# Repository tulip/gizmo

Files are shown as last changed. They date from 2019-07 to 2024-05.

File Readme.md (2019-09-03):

# Micro Word Clock v2

## Arduino IDE setup (must do for programming with AVRISP and Arduino)
- Download the latest version of the [Arduino IDE](https://www.arduino.cc/en/main/software)
- `cd ~/Documents/Arduino && mkdir hardware`
- cd into `hardware` clone [this repository](https://github.com/carlosefr/atmega) into it
- Restart the Arduino IDE, you should see `Tools > Board > ATMega328` and some other things show up
<p align="center">
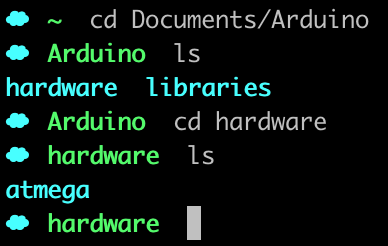
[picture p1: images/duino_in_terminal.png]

</p>

## Upload instructions with AVRISP MKII programmer

##### Burning the bootloader
- Plug in the Gizmo so that it is powered externally - the AVRISP MKII will **not** work if it is not powered externally
- Plug in the AVRISP, select `Tools > Programmer > AVRISP mkII`
- Plug in ICSP header from AVRISP to ICSP header on Gizmo (ICSP labels on Gizmo are on back of board)
- Select `Tools > Board > ATmega328/328p`
- Select `Tools > Processor > ATmega328p`
- Select `Tools > Clock > Internal 8 MHz`
- If everything is good, you should see a green light at the bottom of the programmer.
- Select `Tools > Burn Bootloader`
- If the programmer is working, you should see a second green light flash as it is programming. 

<p align="center">
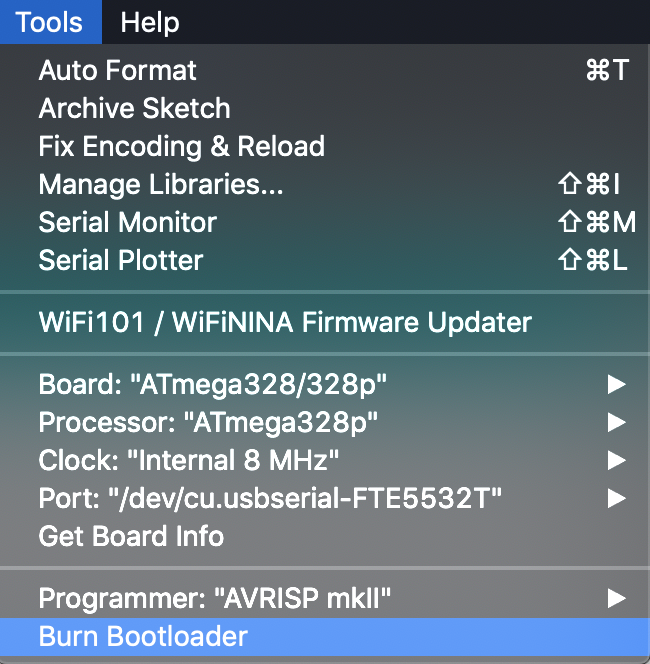
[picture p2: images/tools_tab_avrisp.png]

</p>

##### Uploading sketch
- Open `MicroWordClock2-Arduino.ino` in Arduino IDE
- Select `Sketch > Upload Using Programmer`
<p align="center">
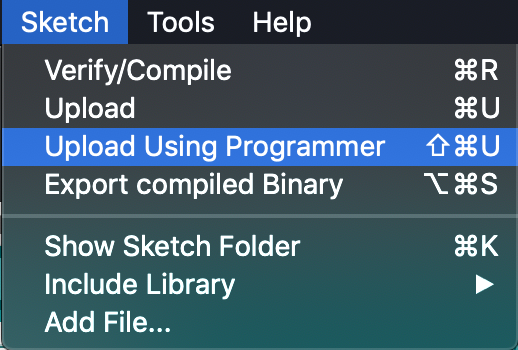
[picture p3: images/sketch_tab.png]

</p>

## Upload instructions with Arduino Uno

##### Setting up the Arduino Uno as an ISP
- Plug in the Arduino, select `Tools > Programmer > Arduino as ISP` and `Tools > Board > Arduino/Genuino Uno`
- Select `File > Examples > ArduinoISP` and see a new script open
- Make sure that the correct port is selected in `Tools > Port`
- On the top left corner of the window, select upload
<p align="center">
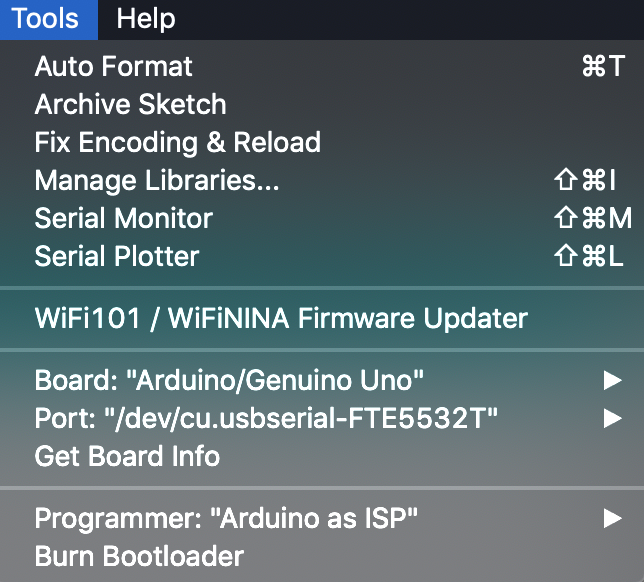
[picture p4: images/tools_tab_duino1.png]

</p>

##### Burning the Bootloader
- Wire up the Arduino to Gizmo's ICSP header, but make sure to wire up power last (Gizmo has the standard ICSP header configuration). Use the following wiring:

| Arduino pin | ICSP header pin |
|---|---|
| 10 | RESET |
| 11 | MOSI |
| 12 | MISO |
| 13 | SCK |
| 5 V | VCC |
| GND | GND |

- Connect a 10uF capacitor between Arduino's RESET pin and GND
- Select `Tools > Board > ATmega328/328p`
- Select `Tools > Processor > ATmega328p`
- Select `Tools > Clock > Internal 8 MHz`
- Select `Tools > Burn Bootloader`
<p align="center">
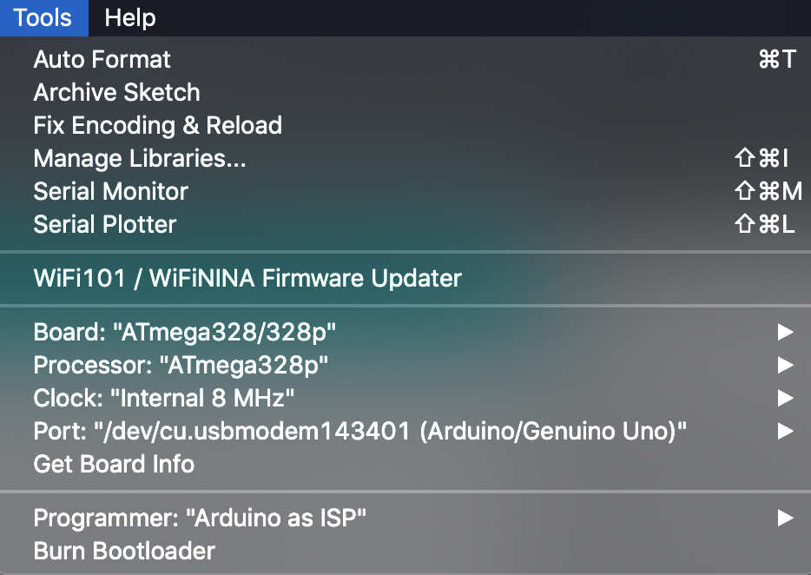
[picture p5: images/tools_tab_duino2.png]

</p>

##### Uploading sketch
- Open `MicroWordClock2-Arduino.ino` in Arduino IDE
- With cap still plugged in and same `Tools` settings as before, select `Sketch > Upload Using Programmer`
- The TX and RX LEDs on the Arduino should start blinking, all LEDs on the Gizmo board should light up initially, then the board should be good to go

##### Troubleshooting 
- Make sure the correct option is selected under `Tools > Board` - should be Arduino Uno only when uploading ISP sketch
- Make sure the connections to the 10uF cap are good - I plugged it into a breadboard and used jumper wires to connect
- If nothing's working, try power cycling

## Setting the time 
- Once the sketch is uploaded, unplug the Arduino/programmer and plug in Gizmo's independent power supply
- Hold down SW1 until words start blinking. To cycle through "quarter past", "half past", etc., press SW1 the number of minutes you want to increment past the time designator
- To set the hour, hold down SW1 again until the current hour starts blinking and cycle through. Once you're done, hold down SW1 until only one LED blinks again

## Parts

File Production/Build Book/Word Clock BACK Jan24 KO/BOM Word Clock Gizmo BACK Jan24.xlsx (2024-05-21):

Reference Designator | Part | MFR | MPN | Link (Old) | Quantity | Notes
U$1, U$2, U$3, U$4, U$5, U$6, U$7, U$8, U$9, U$10, U$11, U$12, U$13, U$14, U$15, U$16, U$17, U$18, U$19, U$20, U$21, U$22, U$23, U$24, U$25, U$26, U$27, U$28, U$29, U$30, U$31, U$32, U$33, U$34, U$35, U$37, U$38, U$39, U$40, U$41, U$42, U$43, U$44, U$45, U$46, U$47, U$48, U$49, U$50, U$51, U$52, U$53, U$54, U$55, U$56, U$57, U$58, U$59, U$60, U$61, U$62, U$63, U$64 | LEDs | Cree | JE2835AWT-00-0000-0B0A0BG840E | https://www.digikey.com/product-detail/en/cree-inc/JE2835AWT-00-0000-0B0A0BG840E/JE2835AWT-00-0000-0B0A0BG840ETR-ND/9974650 | 63
S1 | Switch | TE Connectivity Alcoswitch Switches | 1-1825027-1 | https://www.digikey.com/product-detail/en/te-connectivity-alcoswitch-switches/1-1825027-1/450-1658-ND/1632544 | 1
U1 | ATmega328P | Microchip | ATmega328P-AU | https://www.alibaba.com/product-detail/integrated-circuit-ATMEGA328P-AU-Microcontroller-flash_60826153173.html | 1
J3 | 2x3 0.1'' Header Pin | Adam Tech | PH2-06-UA | https://www.digikey.com/product-detail/en/adam-tech/PH2-06-UA/2057-PH2-06-UA-ND/9830396 | 1
J1 | 1x5 0.1" Header Pin (Male) | Adam Tech | PH1-05-UA | https://www.digikey.com/product-detail/en/adam-tech/PH1-05-UA/2057-PH1-05-UA-ND/9830343 | 1
- | 1x8 0.1" Header Pin (Male) | HOUAC | 1625-1140CNG0S150001 |  | 4 | Installed in J4/J5/J6/J7 during assembly.
J4, J5, J6, J7 | 1x8 0.1" Header Pin (Female) | Sullins Connector Solutions | PPTC081LFBN-RC | https://www.digikey.com/product-detail/en/sullins-connector-solutions/PPTC081LFBN-RC/S7006-ND/810147 | 4
R1, R2, R3, R4, R5, R6, R7, R8 | 0603 51ohm Resistor | Bourns Inc. | CR0603-JW-510ELF | https://www.digikey.com/product-detail/en/bourns-inc/CR0603-JW-510ELF/CR0603-JW-510ELFCT-ND/3925369 | 8
R9 | 0603 1M Resistor | Vishay Beyschlag | MCT0603-1.00M-CFCT | https://www.digikey.com/product-detail/en/vishay-beyschlag/MCT06030C1004FP500/MCT0603-1.00M-CFCT-ND/2607877 | 1
L1 | 0603 120 Ohm Ferrite Bead | TDK | MAF1608GAD601CT000 | https://www.mouser.com/ProductDetail/TDK/MAF1608GAD601CT000 | 1
C1 | 0603 220 nF Capacitor | Samsung Electro-Mechanics | CL10B224KP8NNNC | https://www.digikey.com/product-detail/en/samsung-electro-mechanics/CL10B224KP8NNNC/1276-2014-2-ND/3887672 | 1
C3 | 0603 4700 pF Capacitor | Samsung Electro-Mechanics | CL10B472KB8NNNC | https://www.digikey.com/product-detail/en/samsung-electro-mechanics/CL10B472KB8NNNC/1276-1098-2-ND/3886756 | 1
C4 | 0603 4.7 uF Capacitor | Samsung Electro-Mechanics | CL10A475MQ8NNNC | https://www.digikey.com/product-detail/en/samsung-electro-mechanics/CL10A475MQ8NNNC/1276-1907-1-ND/3889993 | 1
C2 | 2.2uF Capacitor | Samsung Electro-Mechanics | CL10A225KQ8NNWC | https://www.digikey.com/product-detail/en/samsung-electro-mechanics/CL10A225KQ8NNWC/1276-1886-2-ND/3887544 | 1
J2 | MicroUSB Jack | Amphenol ICC FCI | 10118193-0001LF | https://www.digikey.com/product-detail/en/amphenol-icc-fci/10118193-0001LF/609-4616-2-ND/2785388 | 1
- | Real-Time Clock & Battery |  | REF FILE 'RTC CANDIDATES' | https://www.amazon.com/HiLetgo-DS3231-Precision-Arduino-Raspberry/dp/B01N1LZSK3 | 1 | Can use same as last production, requirements: DS3231 RTC, 4 Female Pin With Battery. Please assemble onto PCB (unlike last production)
- | MicroUSB Cable | Shenzhen Hezhongxin Electronics Co., Ltd | HSX-003M | https://www.alibaba.com/product-detail/small-USB-shielded-high-speed-2_62016105964.html?s=p | 1 | Alternate Part Requested, requirements: ~90CM, Black, USB-A Male <> Micro-USB Male, Low-Cost

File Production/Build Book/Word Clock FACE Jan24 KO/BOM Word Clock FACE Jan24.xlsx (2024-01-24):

Reference Designator | Part | Quantity | MFR | MPN | Notes
J1, J2, J3, J4 | 1x8 0.1" Header Pin (Female) | 4 | SparkFun | PRT-11543 | Part Discontinued: Potential Alt SparkFun PRT-21471, but needs verification. Other Alt Parts are also OK. Waiting for drawing from manufacturer.

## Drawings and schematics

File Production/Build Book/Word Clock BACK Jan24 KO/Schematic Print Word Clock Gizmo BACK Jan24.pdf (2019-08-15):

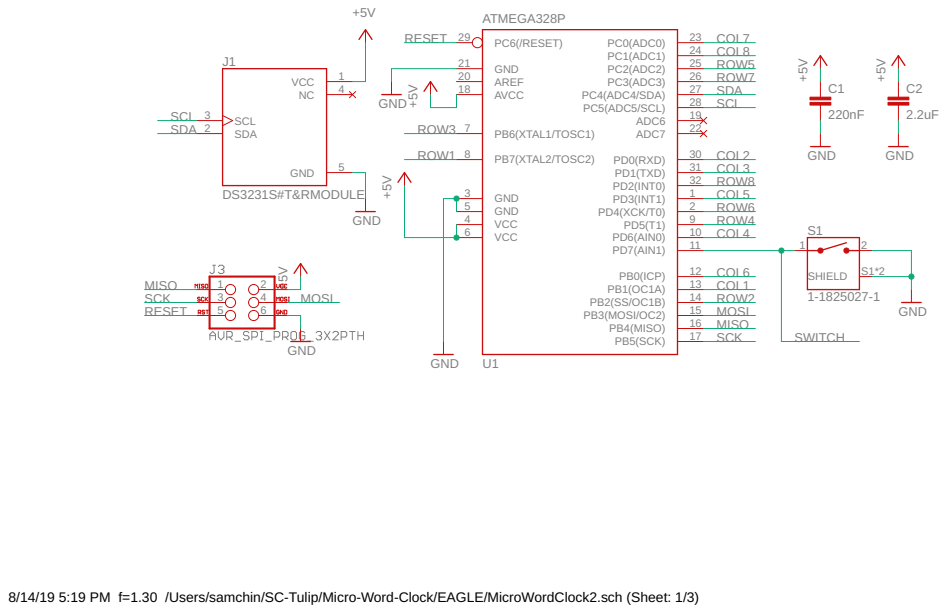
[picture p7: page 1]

8/14/19 5:19 PM f=1.30 /Users/samchin/SC-Tulip/Micro-Word-Clock/EAGLE/MicroWordClock2.sch (Sheet: 1/3)

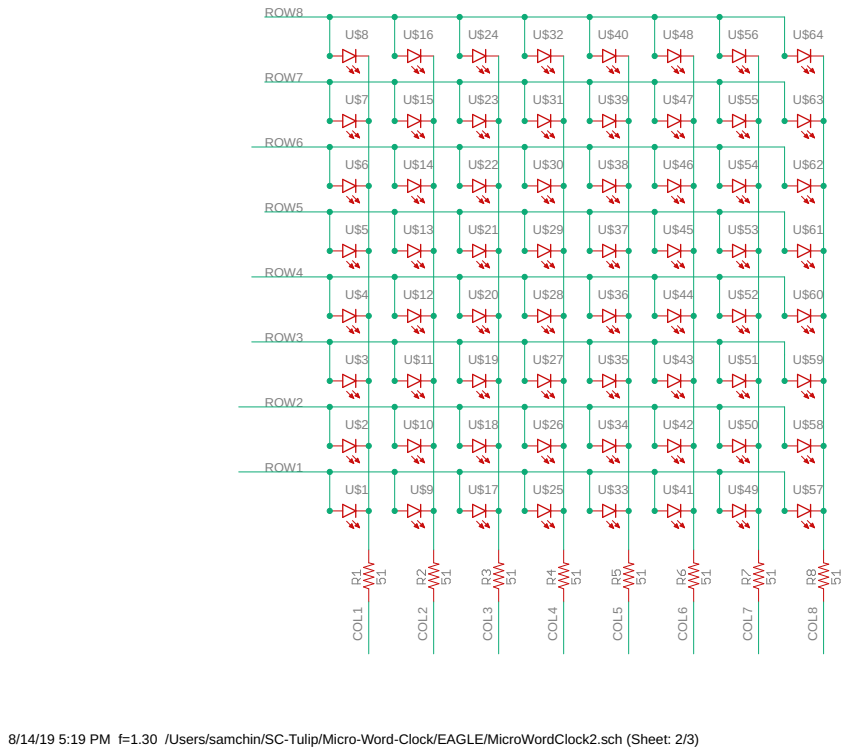
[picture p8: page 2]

8/14/19 5:19 PM f=1.30 /Users/samchin/SC-Tulip/Micro-Word-Clock/EAGLE/MicroWordClock2.sch (Sheet: 2/3)

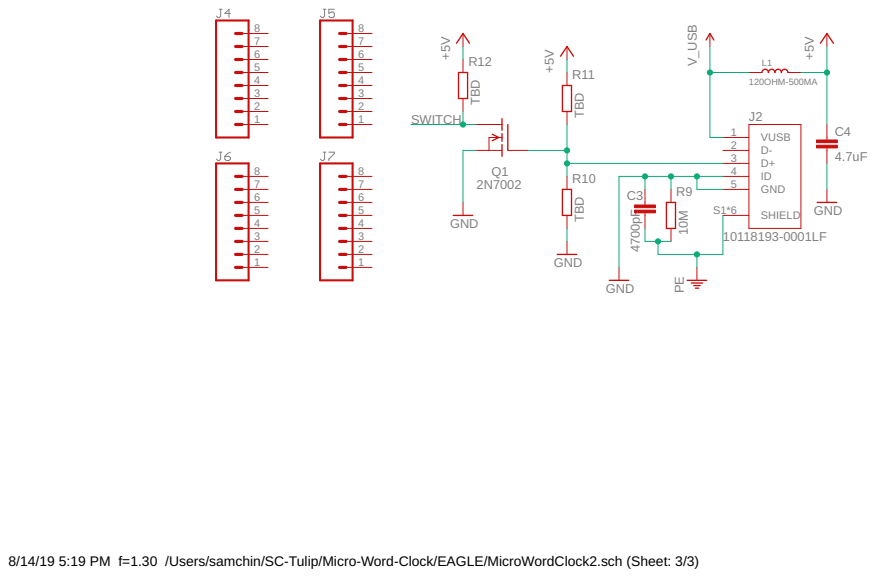
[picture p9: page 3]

8/14/19 5:19 PM f=1.30 /Users/samchin/SC-Tulip/Micro-Word-Clock/EAGLE/MicroWordClock2.sch (Sheet: 3/3)

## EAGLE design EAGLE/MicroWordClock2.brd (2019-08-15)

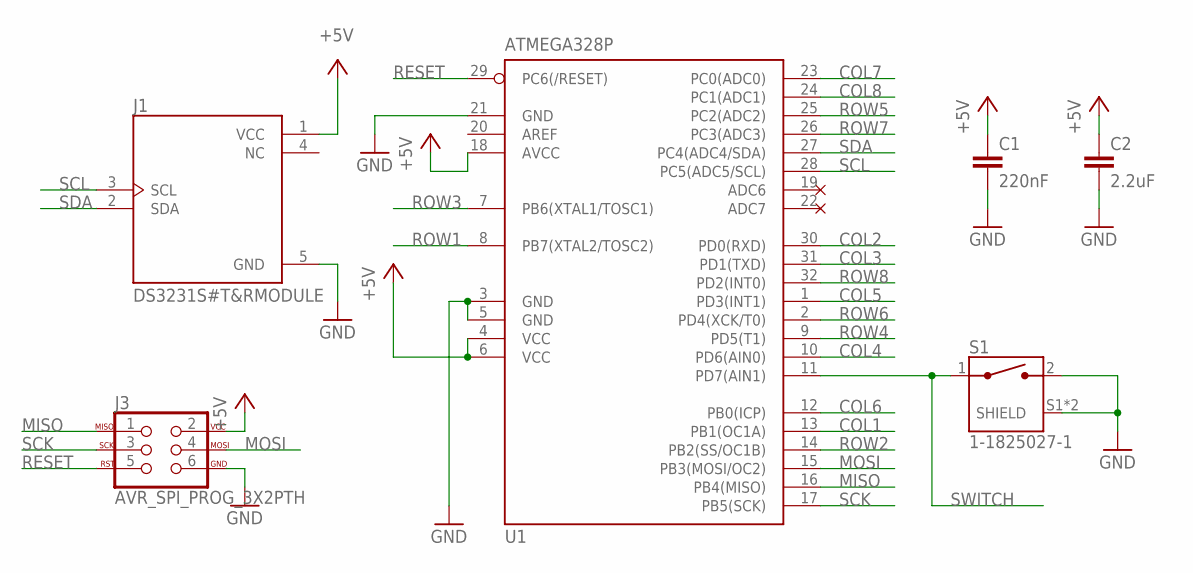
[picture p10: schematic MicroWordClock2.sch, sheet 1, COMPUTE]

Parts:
C1: 220nF; C0603
C2: 2.2uF; C0603
J1: DS3231S#T&RMODULE; 1X05
J3: AVR_SPI_PROG_3X2PTH; 2X3
S1: 1-1825027-1; SW_1-1825027-1
U1: ATMEGA328P; TQFP32-08

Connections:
+5V: C1.1, C2.1, J1.1 (VCC), J3.2, U1.4 (VCC), U1.6 (VCC), U1.18 (AVCC); also elsewhere on the board
COL1: U1.13 (PB1(OC1A)); also elsewhere on the board
COL2: U1.30 (PD0(RXD)); also elsewhere on the board
COL3: U1.31 (PD1(TXD)); also elsewhere on the board
COL4: U1.10 (PD6(AIN0)); also elsewhere on the board
COL5: U1.1 (PD3(INT1)); also elsewhere on the board
COL6: U1.12 (PB0(ICP)); also elsewhere on the board
COL7: U1.23 (PC0(ADC0)); also elsewhere on the board
COL8: U1.24 (PC1(ADC1)); also elsewhere on the board
GND: C1.2, C2.2, J1.5 (GND), J3.6, S1.2, S1.S1 (SHIELD), S1.S2 (SHIELD), U1.3 (GND), U1.5 (GND), U1.21 (GND); also elsewhere on the board
MISO: J3.1, U1.16 (PB4(MISO))
MOSI: J3.4, U1.15 (PB3(MOSI/OC2))
RESET: J3.5, U1.29 (PC6(/RESET))
ROW1: U1.8 (PB7(XTAL2/TOSC2)); also elsewhere on the board
ROW2: U1.14 (PB2(SS/OC1B)); also elsewhere on the board
ROW3: U1.7 (PB6(XTAL1/TOSC1)); also elsewhere on the board
ROW4: U1.9 (PD5(T1)); also elsewhere on the board
ROW5: U1.25 (PC2(ADC2)); also elsewhere on the board
ROW6: U1.2 (PD4(XCK/T0)); also elsewhere on the board
ROW7: U1.26 (PC3(ADC3)); also elsewhere on the board
ROW8: U1.32 (PD2(INT0)); also elsewhere on the board
SCK: J3.3, U1.17 (PB5(SCK))
SCL: J1.3 (SCL), U1.28 (PC5(ADC5/SCL))
SDA: J1.2 (SDA), U1.27 (PC4(ADC4/SDA))
SWITCH: S1.1, U1.11 (PD7(AIN1)); also elsewhere on the board

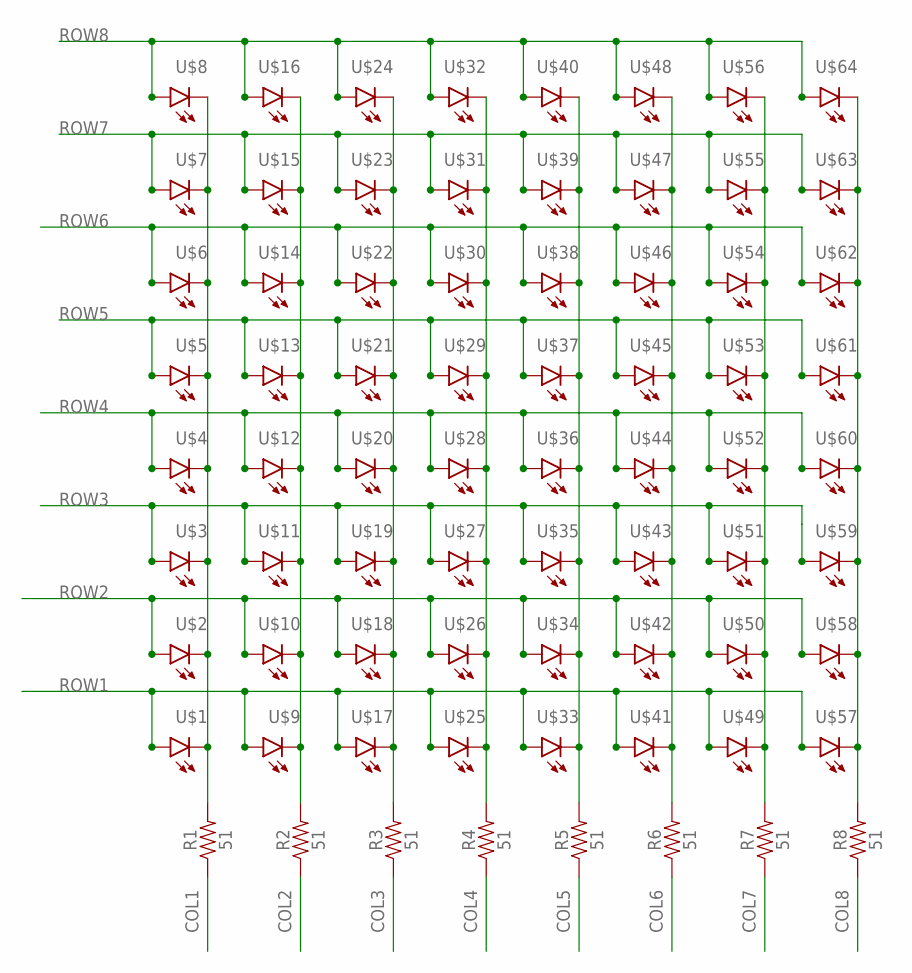
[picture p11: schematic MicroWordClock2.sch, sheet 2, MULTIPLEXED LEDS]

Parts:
R1, R2, R3, R4, R5, R6, R7, R8: 51; 0603
U$1, U$2, U$3, U$4, U$5, U$6, U$7, U$8, U$9, U$10, U$11, U$12, U$13, U$14, U$15, U$16, U$17, U$18, U$19, U$20, U$21, U$22, U$23, U$24, U$25, U$26, U$27, U$28, U$29, U$30, U$31, U$32, U$33, U$34, U$35, U$36, U$37, U$38, U$39, U$40, U$41, U$42, U$43, U$44, U$45, U$46, U$47, U$48, U$49, U$50, U$51, U$52, U$53, U$54, U$55, U$56, U$57, U$58, U$59, U$60, U$61, U$62, U$63, U$64: WHITE; 1113(2835METRIC)

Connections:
COL1: R1.1; also elsewhere on the board
COL2: R2.1; also elsewhere on the board
COL3: R3.1; also elsewhere on the board
COL4: R4.1; also elsewhere on the board
COL5: R5.1; also elsewhere on the board
COL6: R6.1; also elsewhere on the board
COL7: R7.1; also elsewhere on the board
COL8: R8.1; also elsewhere on the board
EE: R8.2, U$57.CATHODE (C), U$58.CATHODE (C), U$59.CATHODE (C), U$60.CATHODE (C), U$61.CATHODE (C), U$62.CATHODE (C), U$63.CATHODE (C), U$64.CATHODE (C)
unnamed: R3.2, U$17.CATHODE (C), U$18.CATHODE (C), U$19.CATHODE (C), U$20.CATHODE (C), U$21.CATHODE (C), U$22.CATHODE (C), U$23.CATHODE (C), U$24.CATHODE (C)
unnamed: R4.2, U$25.CATHODE (C), U$26.CATHODE (C), U$27.CATHODE (C), U$28.CATHODE (C), U$29.CATHODE (C), U$30.CATHODE (C), U$31.CATHODE (C), U$32.CATHODE (C)
unnamed: R5.2, U$33.CATHODE (C), U$34.CATHODE (C), U$35.CATHODE (C), U$36.CATHODE (C), U$37.CATHODE (C), U$38.CATHODE (C), U$39.CATHODE (C), U$40.CATHODE (C)
unnamed: R6.2, U$41.CATHODE (C), U$42.CATHODE (C), U$43.CATHODE (C), U$44.CATHODE (C), U$45.CATHODE (C), U$46.CATHODE (C), U$47.CATHODE (C), U$48.CATHODE (C)
unnamed: R7.2, U$49.CATHODE (C), U$50.CATHODE (C), U$51.CATHODE (C), U$52.CATHODE (C), U$53.CATHODE (C), U$54.CATHODE (C), U$55.CATHODE (C), U$56.CATHODE (C)
unnamed: R1.2, U$1.CATHODE (C), U$2.CATHODE (C), U$3.CATHODE (C), U$4.CATHODE (C), U$5.CATHODE (C), U$6.CATHODE (C), U$7.CATHODE (C), U$8.CATHODE (C)
unnamed: R2.2, U$9.CATHODE (C), U$10.CATHODE (C), U$11.CATHODE (C), U$12.CATHODE (C), U$13.CATHODE (C), U$14.CATHODE (C), U$15.CATHODE (C), U$16.CATHODE (C)
ROW1: U$1.ANODE (A), U$9.ANODE (A), U$17.ANODE (A), U$25.ANODE (A), U$33.ANODE (A), U$41.ANODE (A), U$49.ANODE (A), U$57.ANODE (A); also elsewhere on the board
ROW2: U$2.ANODE (A), U$10.ANODE (A), U$18.ANODE (A), U$26.ANODE (A), U$34.ANODE (A), U$42.ANODE (A), U$50.ANODE (A), U$58.ANODE (A); also elsewhere on the board
ROW3: U$3.ANODE (A), U$11.ANODE (A), U$19.ANODE (A), U$27.ANODE (A), U$35.ANODE (A), U$43.ANODE (A), U$51.ANODE (A), U$59.ANODE (A); also elsewhere on the board
ROW4: U$4.ANODE (A), U$12.ANODE (A), U$20.ANODE (A), U$28.ANODE (A), U$36.ANODE (A), U$44.ANODE (A), U$52.ANODE (A), U$60.ANODE (A); also elsewhere on the board
ROW5: U$5.ANODE (A), U$13.ANODE (A), U$21.ANODE (A), U$29.ANODE (A), U$37.ANODE (A), U$45.ANODE (A), U$53.ANODE (A), U$61.ANODE (A); also elsewhere on the board
ROW6: U$6.ANODE (A), U$14.ANODE (A), U$22.ANODE (A), U$30.ANODE (A), U$38.ANODE (A), U$46.ANODE (A), U$54.ANODE (A), U$62.ANODE (A); also elsewhere on the board
ROW7: U$7.ANODE (A), U$15.ANODE (A), U$23.ANODE (A), U$31.ANODE (A), U$39.ANODE (A), U$47.ANODE (A), U$55.ANODE (A), U$63.ANODE (A); also elsewhere on the board
ROW8: U$8.ANODE (A), U$16.ANODE (A), U$24.ANODE (A), U$32.ANODE (A), U$40.ANODE (A), U$48.ANODE (A), U$56.ANODE (A), U$64.ANODE (A); also elsewhere on the board

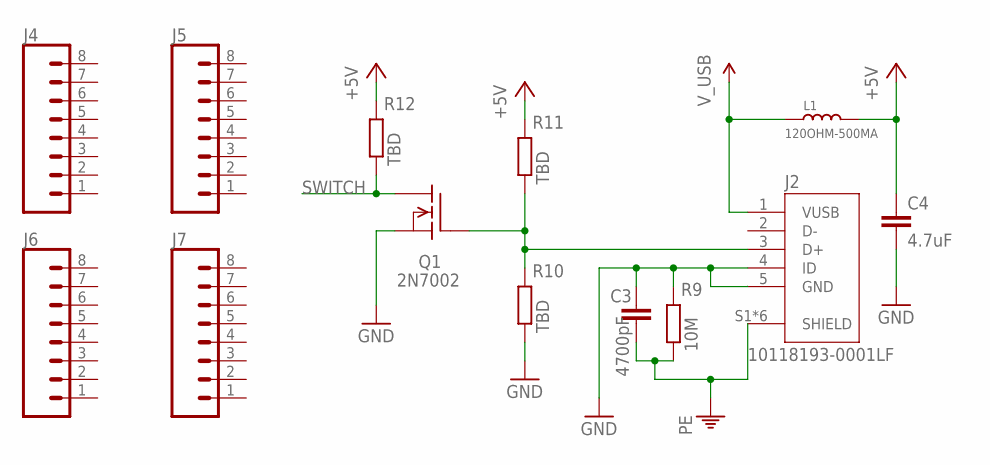
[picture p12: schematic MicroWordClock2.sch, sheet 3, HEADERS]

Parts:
C3: 4700pF; C0603
C4: 4.7uF; C0603
J2: 10118193-0001LF; FCI_10118193-0001LF
J4, J5, J6, J7: CONN_08"; 1X08
L1: 120OHM-500MA; L0603
Q1: 2N7002; SOT23
R9: 10M; R0603
R10, R11, R12: TBD; R0603

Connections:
+5V: C4.1, L1.2, R11.2, R12.2; also elsewhere on the board
GND: C3.1, C4.2, J2.4 (ID), J2.5 (GND), Q1.2 (S), R9.2, R10.1; also elsewhere on the board
unnamed: J2.3 (D+), Q1.1 (G), R10.2, R11.1
PE: C3.2, J2.S1 (SHIELD), J2.S2 (SHIELD), J2.S3 (SHIELD), J2.S4 (SHIELD), J2.S5 (SHIELD), J2.S6 (SHIELD), R9.1
SWITCH: Q1.3 (D), R12.1; also elsewhere on the board
V_USB: J2.1 (VUSB), L1.1

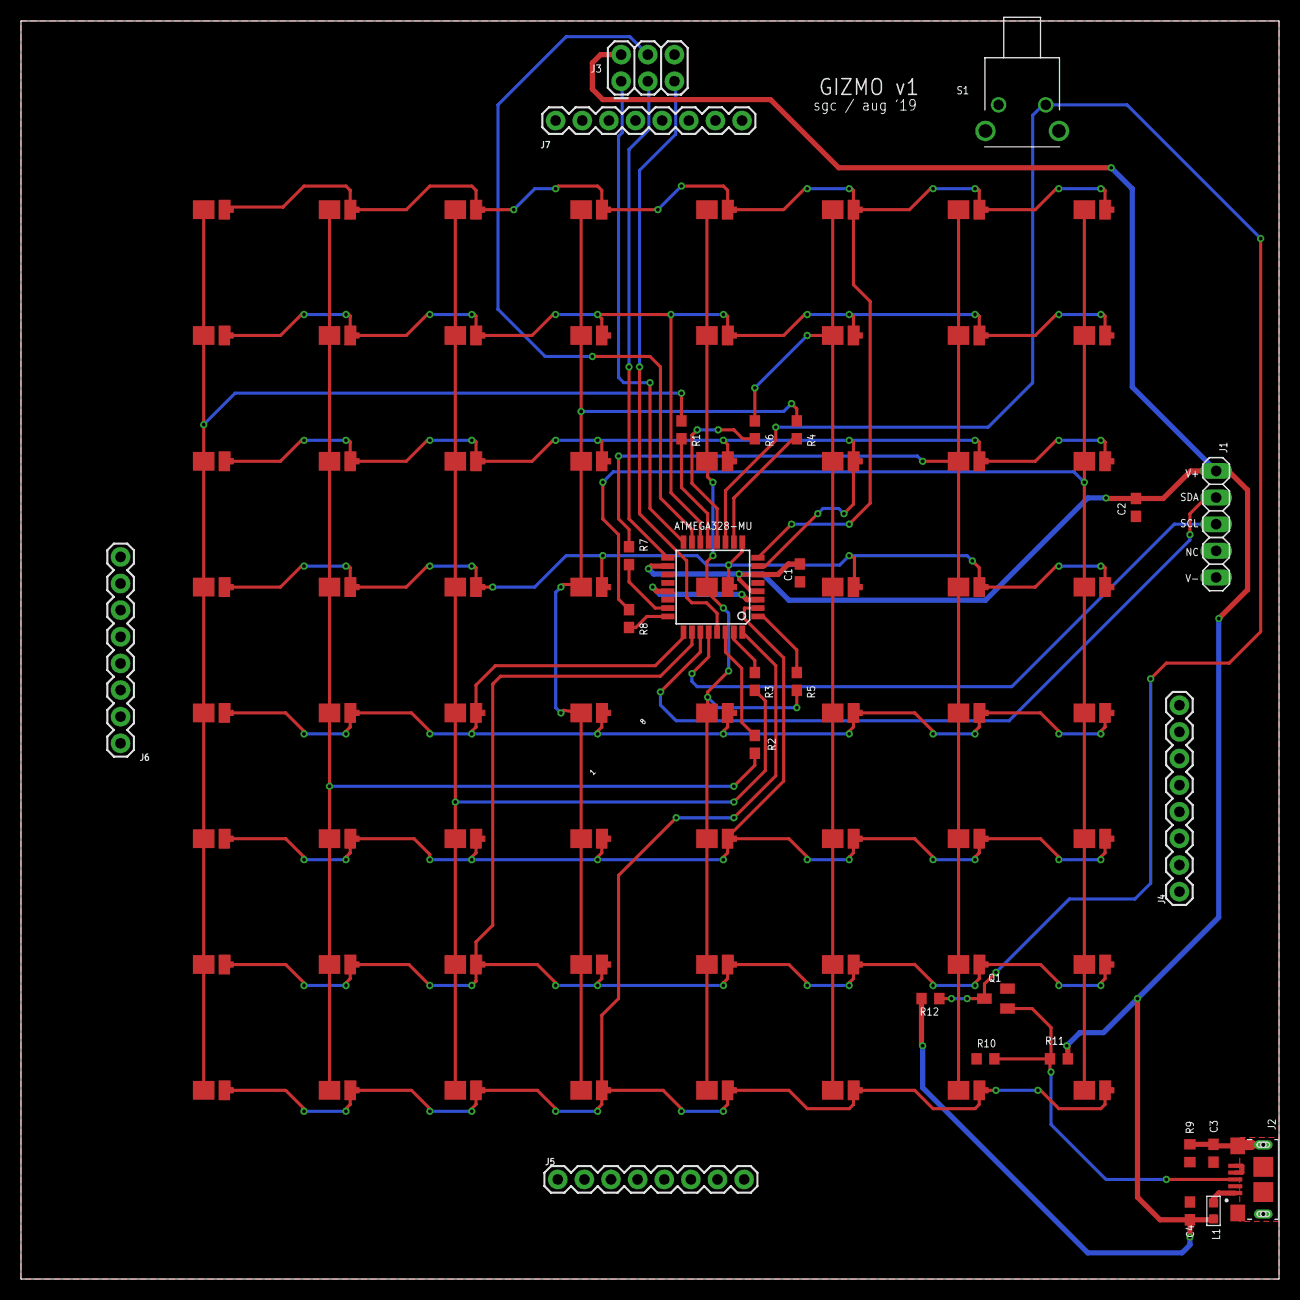
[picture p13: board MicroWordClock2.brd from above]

Board: 2 copper layers, 120.0 x 120.0 mm, 91 parts (0 on the bottom side), 36 nets.

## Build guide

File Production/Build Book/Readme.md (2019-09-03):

# Production Tools for Gizmo

## Using the Hex File

### Uploading the Hex File Using `avrdude`

You should type the following to program it:
From the top level directory, navigate to the hex file in the production folder: 
`cd Micro-Word-Clock/Production`

Then, connect everything according to the [Top Level Readme](https://github.com/tulip/gizmo) instructions. Once everything is connected, you can run the following: 
`avrdude -c avrispmkII -p ATmega328P -e -U flash:w:MicroWordClock2-Arduino.ino.hex`

### Expected Behavior
You should be able to tell your gizmo has flashed correctly if you can perform the following tasks:
- **No Flicker** - Watch for 1min and see no flicker
- **MCU HB** - Blinks first tulip something to confirm MCUs are programmed correctly - this is also the behavior of a broken/not-programmed RTC
- **Minutes Good** - Long button press (>2s)  the minute value blink. Each minute is a press, so pressing 5 times should change the value of the minute.
- **Hours Good** - Long button press (>2s) makes the minute value blink. Another long hold makes the hours blink. Will program - long hold will set it, press quickly to change numbers. 
- **RTC Good** - RTC time persists after a restart
- **NO RTC Programmable** - If there is no RTC, will initialize as blinking"TWELVE" and still be able to be set normally. Should keep time normally. 
- **ADD RTC OK** - Adding a known good RTC should immediately switch the time to the time programmed on the RTC.

NOTE: No RTC hot unplugging! Hot unplugging can induce a complete reset of the RTC. This behavior can be replicated in the original code and seems to occur after multiple hot unplugs. If you need to remove the RTC, unplug the device completely and then remove the RTC.

## RTC Programmer

### How to Connect the RTC to the Gateway

This script is meant to be used on a Tulip Gateway. The gateway should be in the following configuration:
- The gateway should be authenticated so that it will have the correct time. 
- **The gateway should have IO500A and IO500B removed and IO501A and IO501B added. Otherwise it will not work.** See page 12 of the gateway schematic included in this directory.
- You should plug the RTC into the following pins. Note that the gateway pins numbers refer to the ones in silk on the gateway.

| Gateway Pin | RTC Pin |
|---|---|
| GPIOA - 1 | SCL |
| GPIOA - 2 | SDA |
| GPIOA - 4 | PWR | 
| OUTPUT- GND | GND |

### How to Program the RTC
Pre-conditions:
- You have the `ProgramRTC.sh` program on the gateway
- You have changed `ProgramRTC.sh` to an executable: `chmod +x ProgramRTC.sh`
- You are logged in as the `root` user.
- You have connected the RTC to the gateway following the above instructions.

### Confirm that the RTC is Plugged in Correctly

Run `i2cdetect -r -y 1`

You should see the following:
```
     0  1  2  3  4  5  6  7  8  9  a  b  c  d  e  f
00:          -- -- -- -- -- -- -- -- -- -- -- -- --
10: -- -- -- -- -- -- -- -- -- -- -- -- -- -- -- --
20: 20 21 -- -- -- -- -- -- -- -- -- -- -- -- -- --
30: -- -- -- -- -- -- -- -- -- -- -- -- -- -- -- --
40: -- -- -- -- -- -- -- -- 48 -- -- -- -- -- -- --
50: 50 -- -- -- -- -- -- -- -- -- -- -- -- -- -- --
60: -- -- -- -- -- -- -- -- 68 -- -- -- -- -- -- --
70: -- -- -- -- -- -- -- -- 
```

Note the 68! If you don't have this your RTC is plugged in incorrectly. 

### Confirm the Date
Make sure that the date is what you expect it to be by running `date`

### Program the RTC!
If everything looks good, you will want to run `./ProgramRTC.sh`

It will output a bunch of text which you can read through to debug. Now you should be able to plug in your RTC to the Gizmo! It is accurate to the second! 

## Notes on i2cset
This programmer works mostly via the command `i2cset`.

A quick example of what is happening: 
`i2cset -f -y 1 0x68 0x00 0x01`
`i2cset -force -no-interactive i2caddress chipaddress value`

- `-f` forces `i2cset` to set a value
- `-y` turns off interactive mode because this is inside a script 
- `0x68` is the i2c address on the gateway (which you can find by using the `i2cdetect` command)
- `0x00` is the address on the chip you're writing to. You will need to reference the [DS3231's datasheet](https://datasheets.maximintegrated.com/en/ds/DS3231.pdf). On page 11 you will see that the the address 00h corresponds to the "Seconds" of the RTC.
- This in sum, means that you are writing it is 1 seconds (0x01) to the  address for seconds (0x00) of the DS3231 which is located at the 0x68 address of the i2cbus on th gateway.

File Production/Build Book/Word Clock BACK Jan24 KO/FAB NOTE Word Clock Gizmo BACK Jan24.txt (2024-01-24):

Material Type: FR4
Layer Count: 2
Material Thickness: .062 inches
Finish Plating: Lead Free Solder
X Dimension: 120mm
Y Dimension: 120mm
Array X Dimension: N/A
Array Y Dimension: N/A
Array Up: N/A
Outer Copper Wt: 1 oz
Inner Copper Wt: N/A
Castellated Holes: No
Min. Castellated Hole Size: N/A
Solder Mask Sides: Both Sides
Solder Mask Color: REFER TO QUOTE
Silkscreen Sides: Top Side
Silkscreen Color: REFER TO QUOTE
Tab Route: No
Scoring: No
Plated Slots: No
Plated Edges: No
Controlled Impedance: No
Controlled Dielectric: No
Gold Fingers: None
ITAR: No
CounterSink: No
# Plated CounterSinks: 0
# Non-Plated CounterSinks: 0
CounterBore: No
# Plated CounterBores: 0
# Non-Plated CounterBores: 0
Certification: IPC Class 2-A600
AS9100: No
Via-In-Pad: None
Blind/Buried Vias: None
Microvias: None
Soldermask Plugged Vias: Yes

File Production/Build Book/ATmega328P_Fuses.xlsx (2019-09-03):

 |  |  |  |  |  | Programming Configuration
 |  |  |  |  |  | (ATxxxx Devices)
Version 1.0
 | Device: | ATMEGA328
 |  | Bit | LOCKBITS | EXTENDED | HIGH | LOW | Calibration | Address | Range
 |  | 7
 |  | 6 |  |  |  |  |  |  | (0 - 7FFF)
 |  | 5 |  |  |  |  |  |  | (0 - 3FF)
 |  | 4
 |  | 3
 |  | 2
 |  | 1
 |  | 0
 |  |  | CF | FD | DB | E2

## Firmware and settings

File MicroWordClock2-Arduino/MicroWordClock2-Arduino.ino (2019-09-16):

#include <Wire.h>
#include "RTClib.h"
#include "TimeLib.h"


// Local includes
#include "pindefs.h"
#include "otherdefs.h"

// Customizable options
#include "english.h" // exchange this for the language you need
boolean blink_enable = true;
boolean blinknow = false;
boolean setonce = false;
#define FREQ_DISPLAY 490 // Hz
#define FREQ_TIMEUPDATE  490 // Hz

volatile int cols[]={ // PC0,PD4,PB6!,PB3,PD5,PB4,PC2,PC3
  MTX_COL1,MTX_COL2,MTX_COL3,MTX_COL4,MTX_COL5,MTX_COL6,MTX_COL7,MTX_COL8}; // ON=LOW
volatile int rows[]={ // PB2,PC1,PD7,PB5,PD2,PD6,PD3,PB7!
  MTX_ROW1,MTX_ROW2,MTX_ROW3,MTX_ROW4,MTX_ROW5,MTX_ROW6,MTX_ROW7,MTX_ROW8}; // ON=HIGH

enum ClockMode {
  NORMAL,
  SET_MIN,
  SET_HRS,
  END,
};

ClockMode clockmode = NORMAL;


volatile char disp[8]={
  0B11111111,
  0B11111111,
  0B11111111,
  0B11111111,
  0B11111111,
  0B11111111,
  0B11111111,
  0B11111111,
};

char testdisp[8]={
  0B11111111,
  0B11111111,
  0B11111111,
  0B11111111,
  0B11111111,
  0B11111111,
  0B11111111,
  0B11111111,
};

// RTC stuff
RTC_DS1307 rtc;
unsigned long disp_sec;
unsigned long disp_min;
unsigned long disp_hrs;

volatile boolean updatenow = false;

boolean buttonState = LOW;
unsigned long buttonMillis = 0;
boolean buttonHandled = true;

void loop() {
  if(updatenow) {
    if ((rtc.isrunning() && disp_min == 3 && clockmode == NORMAL) || (rtc.isrunning() && disp_min == 9 && clockmode == NORMAL)){
      TCNT1 = 0;
    }
    updateTime();
    prepareDisplay();
    updatenow = false;
  }

  if(!rtc.isrunning() && !setonce){
    clockmode = SET_HRS;
  }
  if(digitalRead(PIN_BUTTON) != buttonState) {
    buttonState = digitalRead(PIN_BUTTON);
    if(buttonState == LOW) { // button was pressed
      buttonMillis = millis();
      buttonHandled = false;
      setonce = true;
    }
    else { // button was released
      buttonHandled = true;
      unsigned long buttonDelay = millis() - buttonMillis;
      if(buttonDelay > 01) { // debounce
        if(buttonDelay < 750) { // simple press
          updatenow = true;
          switch(clockmode) {
          case NORMAL:
            blink_enable = !blink_enable;
            blinknow = true;
            TCNT1 = 0;
            break;
          case SET_MIN:
            if(rtc.isrunning())
              rtc.adjust(rtc.now().unixtime() + 1*60);
            else
              adjustTime(60);
            blinknow = true;
            TCNT1 = 0;
            break;
          case SET_HRS:
            if(rtc.isrunning())
              rtc.adjust(rtc.now().unixtime() + 1*60*60);
            else
              adjustTime(60*60);
            blinknow = true;
            TCNT1 = 0;
            break;
          }
        }
      }
    }
  }
  else {
    if(buttonState == LOW && !buttonHandled) { // button is being pressed
      unsigned long buttonDelay = millis() - buttonMillis;
      if(buttonDelay > 2000) {
        blinknow = false;
        TCNT1 = 0;
        clockmode = (ClockMode)((int)clockmode + 1);
        if(clockmode == END)
          clockmode = NORMAL;
        buttonHandled = true;
        updatenow = true;
      }
    }
  }
}

void updateTime() {
  // Adjust 2.5 minutes = 150 seconds forward
  // So at 12:03 it already reads "five past 12"
  
  if(rtc.isrunning()){
    DateTime now = rtc.now().unixtime() + 150;
    disp_sec = now.second();
    disp_min = now.minute();
    disp_hrs = now.hour();
  }
  else{
    disp_sec = second();
    disp_min = minute();
    disp_hrs = hour();
  }
    
  disp_min /= 5;

  if(disp_min >= min_offset)
    ++disp_hrs %= 12;
  else
    disp_hrs   %= 12;
  
}

void prepareDisplay() {
  blinknow = !blinknow;
  FOR_ALLROWS {
    disp[r]=B00000000;
    FOR_ALLCOLS {
      if((clockmode != SET_MIN || !blinknow))
          disp[r] |= minutes[disp_min][r] & (B10000000 >> c);
      if((clockmode != SET_HRS || !blinknow))
          disp[r] |= hours  [disp_hrs][r] & (B10000000 >> c); 
      if(clockmode == NORMAL && blink_enable && !blinknow)
        disp[r] |= blinky[r];
    }
  }
}

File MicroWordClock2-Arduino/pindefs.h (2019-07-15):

// Matching LED rows/columns to the matrix's pins
// to microcontroller ports to microcontroller pins
// to Arduino pin notation. Whew.

// PORTB: Digital pins (offset 8), PB6/PB7 are XTAL
// PORTC: Analog pins (no offset), PC6 is RESET, PC7 nonexistent
// PORTD: Digital pins (no offset)

// Pin definitions
#define PIN_BUTTON PD7

// Mapping Matrix Row/Col numbers to Matrix pins
#define MTX_ROW1 MTX_PIN9
#define MTX_ROW2 MTX_PIN14
#define MTX_ROW3 MTX_PIN8
#define MTX_ROW4 MTX_PIN12
#define MTX_ROW5 MTX_PIN1
#define MTX_ROW6 MTX_PIN7
#define MTX_ROW7 MTX_PIN2
#define MTX_ROW8 MTX_PIN5

#define MTX_COL1 MTX_PIN13
#define MTX_COL2 MTX_PIN3
#define MTX_COL3 MTX_PIN4
#define MTX_COL4 MTX_PIN10
#define MTX_COL5 MTX_PIN6
#define MTX_COL6 MTX_PIN11
#define MTX_COL7 MTX_PIN15
#define MTX_COL8 MTX_PIN16

#define MTX_PIN1  SIG_B1
#define MTX_PIN2  SIG_B2
#define MTX_PIN3  SIG_B3
#define MTX_PIN4  SIG_B4
#define MTX_PIN5  SIG_B5
#define MTX_PIN6  SIG_B6
#define MTX_PIN7  SIG_B7
#define MTX_PIN8  SIG_B8
#define MTX_PIN9  SIG_A8
#define MTX_PIN10 SIG_A7
#define MTX_PIN11 SIG_A6
#define MTX_PIN12 SIG_A5
#define MTX_PIN13 SIG_A4
#define MTX_PIN14 SIG_A3
#define MTX_PIN15 SIG_A2
#define MTX_PIN16 SIG_A1

#define SIG_A1  PC1
#define SIG_A2  PC0
#define SIG_A3  PB2
#define SIG_A4  PB1
#define SIG_A5  PD5
#define SIG_A6  PB0
#define SIG_A7  PD6
#define SIG_A8  PB7
#define SIG_B1  PC2
#define SIG_B2  PC3
#define SIG_B3  PD0
#define SIG_B4  PD1
#define SIG_B5  PD2
#define SIG_B6  PD3
#define SIG_B7  PD4
#define SIG_B8  PB6

#define PB0  8
#define PB1  9
#define PB2 10
#define PB3 11
#define PB4 12
#define PB5 13
#define PB6 A6 //XTAL1
#define PB7 A7 //XTAL2

#define PC0 A0
#define PC1 A1
#define PC2 A2
#define PC3 A3
#define PC4 A4
#define PC5 A5

#define PD0 0
#define PD1 1
#define PD2 2
#define PD3 3
#define PD4 4
#define PD5 5
#define PD6 6

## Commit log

2019-06-06 initial edits to update the existing layout with the same components as the original
    [MicroWordClock2.brd, MicroWordClock2.sch]
2019-06-08 board with new footprints for switch, microusb and clock & complete routing
    [MicroWordClock2.brd, MicroWordClock2.sch]
2019-06-08 fixing some stray wires, adding the tulip logo to the back
    [MicroWordClock2.brd]
2019-06-08 adding tented vias + add additional board information text
    [MicroWordClock2.brd]
2019-06-08 adding serial number landing area
    [MicroWordClock2.brd]
2019-06-08 fixing some erc issues
    [MicroWordClock2.sch]
2019-06-08 fixing the erc and drc of AVCC
    [MicroWordClock2.brd, MicroWordClock2.sch]
2019-06-11 adding the dxf
    [MicroWordClock2.brd]
2019-06-11 half way done with rerouting
    [MicroWordClock2.brd]
2019-06-11 done rerouting everything except for power
    [MicroWordClock2.brd]
2019-06-13 initial routing + pours. created a variant for the no pops
    [MicroWordClock2.brd, MicroWordClock2.sch]
2019-06-13 fixing up the lettering
    [MicroWordClock2.brd]
2019-06-13 Word Clock Face board added
2019-06-18 adding the LED library
2019-07-11 fixed cols 2 and 3
    [pindefs.h, setup.ino]
2019-07-12 fixed lettering for 10
    [MicroWordClock2-Arduino.ino, setup.ino]
2019-07-12 arduino 1.8.9 upload instruct edits
2019-08-14 Fixing initial bugs from V0 - pad sizes, SCL/SDA line switch see issue #4 for full list. Also added updated schematic"
    [MicroWordClock2.brd, MicroWordClock2.sch]
2019-08-29 Fixing flicker, changing default no-RTC-behavior to just be a flashing tulip
    [MicroWordClock2-Arduino.ino]
2019-08-29 Readme formatting and adding info about i2cset
2019-08-29 Some more readme formatting, updating the RTC programmer to initialize pins to power the RTC
2019-09-03 adding the fuses doc
    [ATmega328P_Fuses.xlsx]
2019-09-03 updating the fuses in the the boards.txt file to be the ones we actually used, removing commented code
2019-09-06 updating word face to have smt headers
    [WordClockFace.sch]
2019-09-12 adding the reset of the timing loop in the display loop to resolve flickering issue sabrina found
    [MicroWordClock2-Arduino.ino]
2019-09-12 committing the tulip face and fixing a header
    [WordClockFace.sch]
2019-09-16 adding the build book for the release of assembly show
2024-01-24 Unpacking path, adding changes for Messe '24
    [ATmega328P_Fuses.xlsx, BOM Word Clock FACE Jan24.xlsx, BOM Word Clock Gizmo BACK Jan24.xlsx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]
2024-05-21 Updated after Production Run 2, Start of Production Run 3
    [BOM Word Clock Gizmo BACK Jan24.xlsx]

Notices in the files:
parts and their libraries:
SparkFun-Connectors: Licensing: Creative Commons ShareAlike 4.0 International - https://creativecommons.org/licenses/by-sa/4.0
